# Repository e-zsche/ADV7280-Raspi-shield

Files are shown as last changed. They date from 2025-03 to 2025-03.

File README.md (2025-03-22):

# ADV7280 based analog video digitizer shield for raspberry pi

Raspberry pi shiel built around the ADV7280 analog video decoder IC. Connection to raspberry pi over
MIPI CSI-2 interface. FFC/FPC connector on the shield has the same pinout as the pi camera connector.

<p float="center">
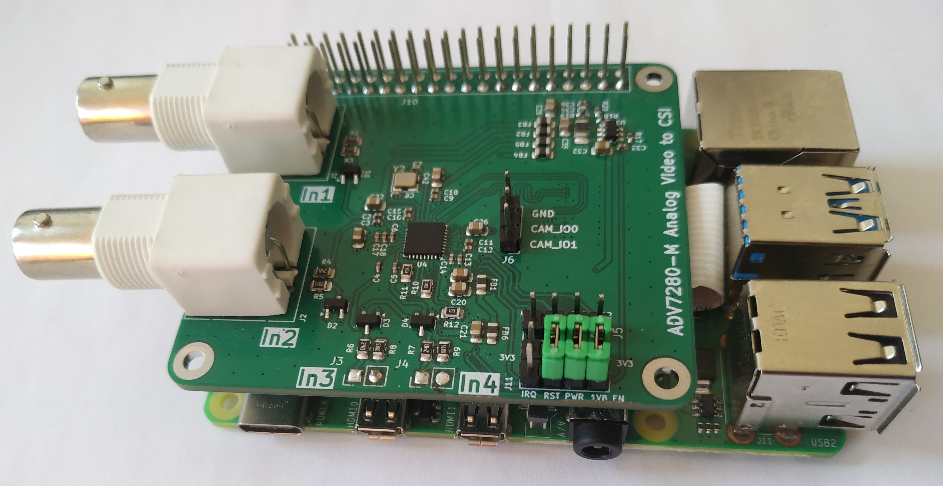
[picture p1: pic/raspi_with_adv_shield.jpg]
  
</p>

One huge advantage the ADV7280 has over similiar analog video decoders is that the drivers are already
present in the standard raspberry pi linux kernel. All you have to do is enable the driver in the
config.txt file. This shield is more or less plug'n'play.

# Hardware

The whole circuit design is copied exactly from the <a href="https://www.analog.com/media/en/technical-documentation/data-sheets/ADV7280.PDF">ADV7280 datasheet</a>

<p float="left">
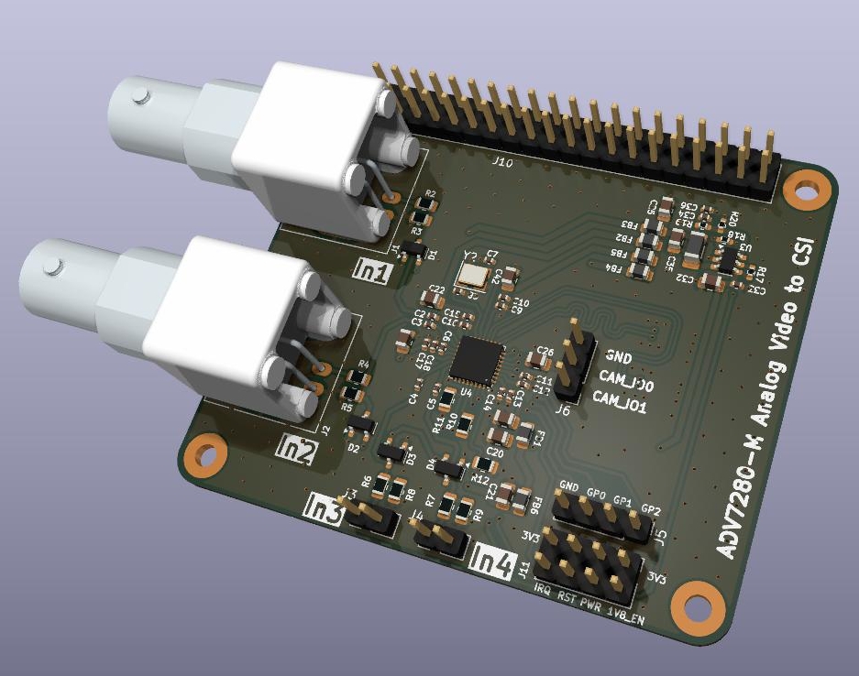
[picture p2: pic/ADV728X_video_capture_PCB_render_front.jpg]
  
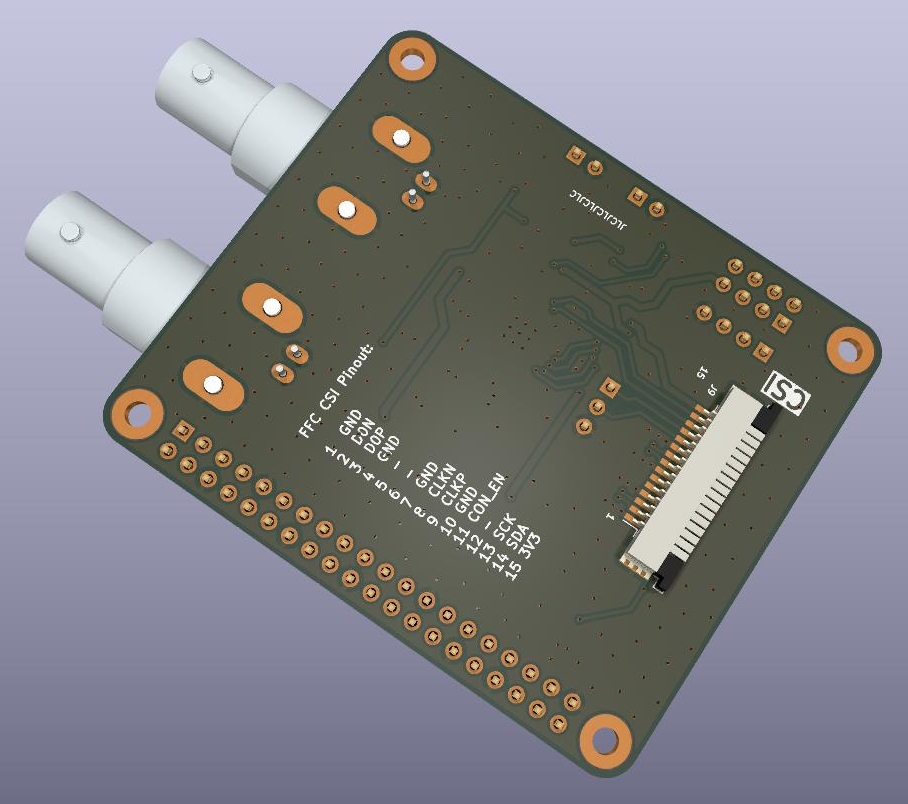
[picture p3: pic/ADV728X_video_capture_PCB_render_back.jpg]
  
</p>

Video inputs are done with BNC connectors. The only reason is that I got these really cheap so I use
them everywhere. All video inputs are terminated with 75R resistors close to the connector. For
protection there are BAT54S diodes installed on all used inputs. Because of space constraints only
inputs 1 - 4 are available on the PCB.

In the beginning I was unsure how to set the RST, PWRDWN pins of the ADV7280 and how important
the power cycling is when booting the IC. That is what the jumper pins near the raspberry pi's
USB connectors are for. Turns out you can leave them all connected to +3.3V all the time.

I was unsure about the CAM_IO1 and CAM_IO2 pins of the raspberry CSI connector as well. The pins
on the pin header can be left unconnected.

The only really critical traces in my opinion are from the CSI output from the IC to the FFC/FPC
camera connector. Looking at the technical specs in the MIPI CSI standard these traces the traces
should have 100R differential impedance (+/- 10%). To get the correct trace width and spacing I
used kicad's builtin calculation tool and the PCB dimensions of the manufacturer. With these I
fiddled around with the calculation until it was close enough.

This design is routed for ordering at JLCPCB (not sponsored!). This is important because different
manufacturers may have different PCB dimensions, which in turn affects the trace impedance of the
CSI traces. Make sure to get this correct, otherwise the CSI connection may not work reliably.

Until now the shield is running fine and I encountered no problems while running.

# Software

All connections this shield needs for running is the CSI connector to the raspberry pi's camera
interface. Enabling the kernel module for this shield is done in the config.txt file:

```
[all]
# enable adv7280
dtoverlay=adv728x-m,adv7280m=1
```

Done! After booting you should get a ne video device.
You can check this with v4l2-ctl command line utility.

```
$ v4l2-ctl --list-devices
$ v4l2-ctl -D -d 0
```

## setting video standard

Video standard is set to NTSC as default. Change it with this command
```
$ v4l2-ctl --set-standard pal
$ v4l2-ctl --set-standard ntsc
```

## changing inputs

Selecting video input source is not straight forward. This is not streamlined in the driver.
Doing this is a little bit hacky, but it works.

```
$ sudo bash -c "echo 0 > /sys/module/adv7180/parameters/dbg_input"
```

Change the number to the input you want to select. 0 corresponds to input 1 and so forth.
You can check the detected input format with

```
$ v4l2-ctl -S
```

## picture adjustment

Here is the interesting part. You can adjust brightness, saturation and so on inside the ADV7280.
No need to fiddle around with i2c registers. When the driver is loaded the corresponding i2c bus
is not exposed for reading or writing. Instead everything is handled through the v4l2-ctl utility.

To list the available settings use one of these commands:

```
$ v4l2-ctl -d <device> -l
$ v4l2-ctl -d <device> -L
```

This gives a description of all available settings and also shows the value range for each setting. If you want to change something use this command:

```
$ v4l2-ctl -d <device> -c <setting>=<value>
```

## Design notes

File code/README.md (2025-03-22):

# Even more control over picture quality

While doing picture adjustment via v4l2-ctl is fine it's not the end of it! You can have even
more control when starting to set values in the ADV7280 registers.

There is only one problem: the kernel has ownership of the I2C interface so you should not be
able to read and write directly on the bus. Well, kind of... There is a really hacky und unsafe
way to get around this. What you need is a small utility package for interfacing with i2c over
the command line.

```
sudo apt install i2c-tools
```

Inside the package are two tools that let us get access to blocked I2C busses: `i2cget` and `i2cset`.
All of this is packed in a messy python library that basically calls the command line tools and
reads the output.

As you can imagine this whole process is really messy as you never check if there is other traffic
on the bus at any time. From what I can tell the ADV7280 gets initialized by the kernel module
at boot time and afterwards it just occupies the bus with no more commands being issued. Until now
there were no crashes because of colliding I2C commands.

You can however make the chip unresponsive by setting some values in the registers. Be warned. Should
this happen and there is no response from the chip you can just reboot and everything works fine again.

## ADV7280 registers

If you want to see the registers and what they do for yourself Analog Devices published the <a href="https://www.analog.com/media/en/technical-documentation/user-guides/adv7280_7281_7282_7283_ug-637.pdf">hardware reference pdf</a>
for the ADV7280 (and similiar). Here you will find all registers with description and what they do

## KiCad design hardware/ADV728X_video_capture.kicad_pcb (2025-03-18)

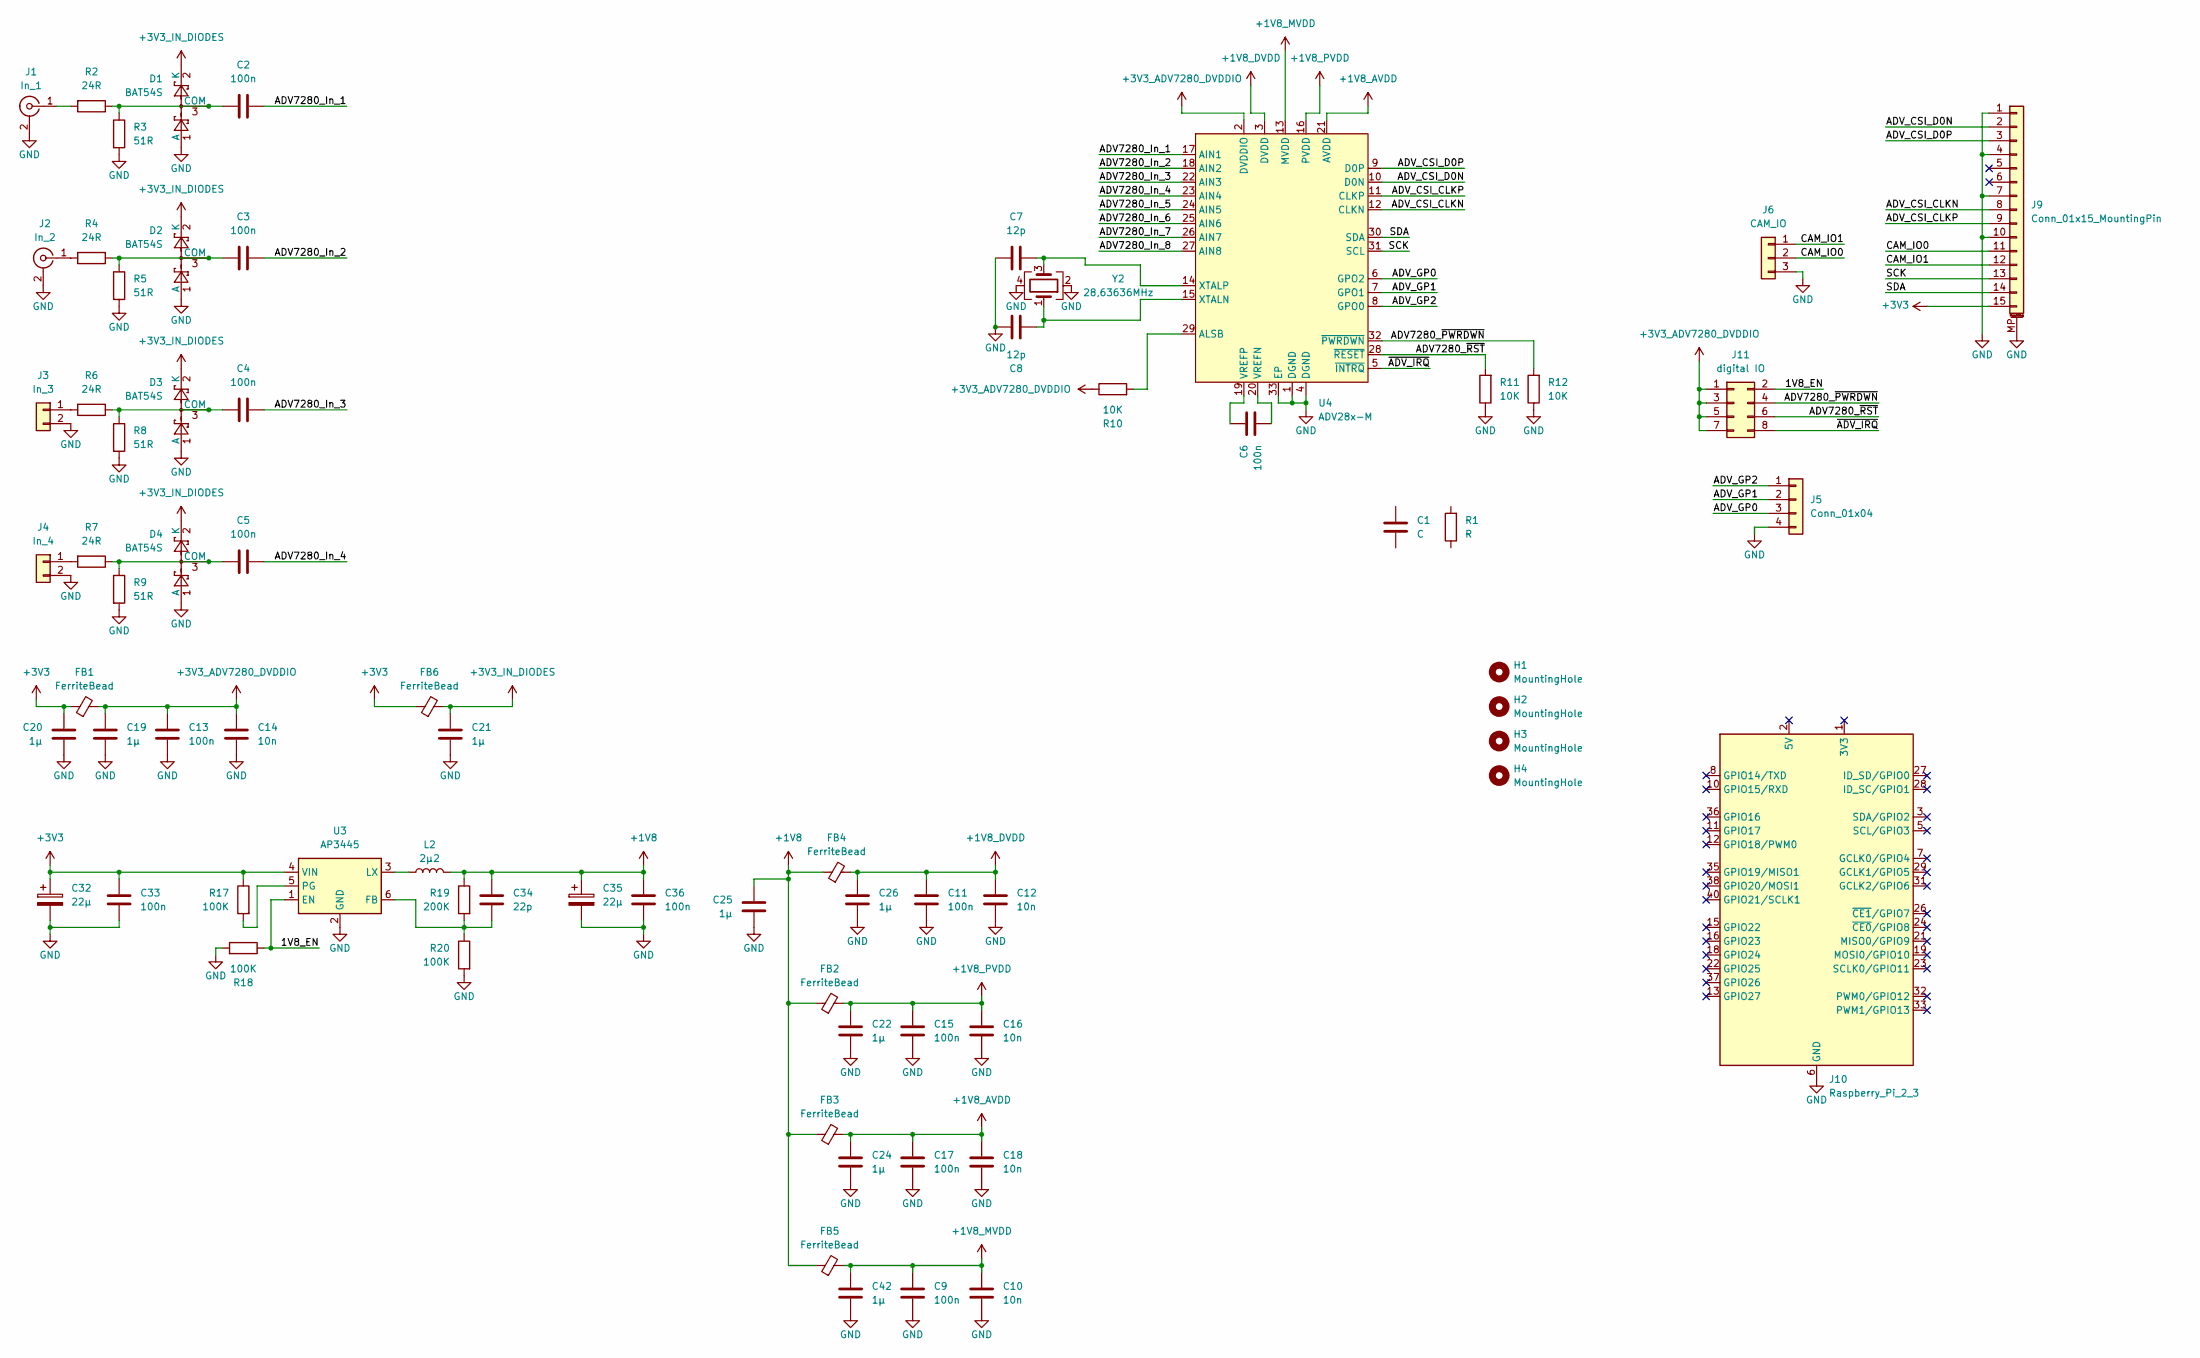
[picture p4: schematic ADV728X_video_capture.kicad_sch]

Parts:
C1: C
C2, C3, C4, C5, C6, C9, C11, C13, C15, C17, C33, C36: 100n; C_0402_1005Metric
C7, C8: 12p; C_0402_1005Metric
C10, C12, C14, C16, C18: 10n; C_0402_1005Metric
C19, C20, C21, C22, C24, C25, C26, C42: 1µ; C_0805_2012Metric
C32, C35: 22µ; C_0805_2012Metric
C34: 22p; C_0402_1005Metric
D1, D2, D3, D4: BAT54S; SOT-23
FB1, FB2, FB3, FB4, FB5, FB6: FerriteBead; L_0805_2012Metric
H1, H2, H3, H4: MountingHole; MountingHole_2.7mm_Pad
J1: In_1; BNC_Amphenol_B6252HB-NPP3G-50_Horizontal
J2: In_2; BNC_Amphenol_B6252HB-NPP3G-50_Horizontal
J3: In_3; PinHeader_1x02_P2.54mm_Vertical
J4: In_4; PinHeader_1x02_P2.54mm_Vertical
J5: Conn_01x04; PinHeader_1x04_P2.54mm_Vertical
J6: CAM_IO; PinHeader_1x03_P2.54mm_Vertical
J9: Conn_01x15_MountingPin; TE_1-84953-5_1x15-1MP_P1.0mm_Horizontal
J10: Raspberry_Pi_2_3; PinHeader_2x20_P2.54mm_Vertical
J11: digital IO; PinHeader_2x04_P2.54mm_Vertical
L2: 2µ2; L_1206_3216Metric_Pad1.22x1.90mm_HandSolder
R1: R
R2, R4, R6, R7: 24R; R_0805_2012Metric
R3, R5, R8, R9: 51R; R_0805_2012Metric
R10, R11, R12: 10K; R_0805_2012Metric
R17, R18, R20: 100K; R_0402_1005Metric_Pad0.72x0.64mm_HandSolder
R19: 200K; R_0402_1005Metric_Pad0.72x0.64mm_HandSolder
U3: AP3445; TSOT-23-6
U4: ADV28x-M; LFCSP-32-1EP_5x5mm_P0.5mm_EP3.6x3.6mm
Y2: 28,63636MHz; Crystal_SMD_3225-4Pin_3.2x2.5mm

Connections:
+1V8: C25.1, C34.1, C35.1, C36.1, FB2.1, FB3.1, FB4.1, FB5.1, L2.2, R19.1
+1V8_AVDD: C17.1, C18.1, C24.1, FB3.2, U4.21 (AVDD)
+1V8_DVDD: C11.1, C12.1, C26.1, FB4.2, U4.3 (DVDD)
+1V8_MVDD: C9.1, C10.1, C42.1, FB5.2, U4.13 (MVDD)
+1V8_PVDD: C15.1, C16.1, C22.1, FB2.2, U4.16 (PVDD)
+3V3: C20.1, C32.1, C33.1, FB1.1, FB6.1, J9.15, R17.1, U3.4 (VIN)
+3V3_ADV7280_DVDDIO: C13.1, C14.1, C19.1, FB1.2, J11.1, J11.3, J11.5, J11.7, R10.1, U4.2 (DVDDIO)
+3V3_IN_DIODES: C21.1, D1.2 (K), D2.2 (K), D3.2 (K), D4.2 (K), FB6.2
/1V8_EN: J11.2, R18.1, U3.1 (EN)
/ADV7280_In_1: C2.2, U4.17 (AIN1)
/ADV7280_In_2: C3.2, U4.18 (AIN2)
/ADV7280_In_3: C4.2, U4.22 (AIN3)
/ADV7280_In_4: C5.2, U4.23 (AIN4)
/ADV7280_In_5: U4.24 (AIN5)
/ADV7280_In_6: U4.25 (AIN6)
/ADV7280_In_7: U4.26 (AIN7)
/ADV7280_In_8: U4.27 (AIN8)
/ADV7280_~PWRDWN: J11.4, R12.2, U4.32 (~PWRDWN)
/ADV7280_~RST: J11.6, R11.2, U4.28 (~RESET)
/ADV_CSI_CLKN: J9.8, U4.12 (CLKN)
/ADV_CSI_CLKP: J9.9, U4.11 (CLKP)
/ADV_CSI_D0N: J9.2, U4.10 (D0N)
/ADV_CSI_D0P: J9.3, U4.9 (D0P)
/ADV_GP0: J5.3, U4.6 (GPO2)
/ADV_GP1: J5.2, U4.7 (GPO1)
/ADV_GP2: J5.1, U4.8 (GPO0)
/CAM_IO0: J6.2, J9.11
/CAM_IO1: J6.1, J9.12
/SCK: J9.13, U4.31 (SCL)
/SDA: J9.14, U4.30 (SDA)
/~ADV_IRQ: J11.8, U4.5 (~INTRQ)
GND: C7.1, C8.1, C9.2, C10.2, C11.2, C12.2, C13.2, C14.2, C15.2, C16.2, C17.2, C18.2, C19.2, C20.2, C21.2, C22.2, C24.2, C25.2, C26.2, C32.2, C33.2, C35.2, C36.2, C42.2, D1.1 (A), D2.1 (A), D3.1 (A), D4.1 (A), J1.2 (Ext), J2.2 (Ext), J3.2, J4.2, J5.4, J6.3, J9.1, J9.4, J9.7, J9.10, J9.MP (MountPin), J10.6 (GND), J10.9 (GND), J10.14 (GND), J10.20 (GND), J10.25 (GND), J10.30 (GND), J10.34 (GND), J10.39 (GND), R3.2, R5.2, R8.2, R9.2, R11.1, R12.1, R18.2, R20.2, U3.2 (GND), U4.1 (DGND), U4.4 (DGND), U4.33 (EP), Y2.2, Y2.4
unnamed: C2.1, D1.3 (COM), R2.1, R3.1
unnamed: C3.1, D2.3 (COM), R4.1, R5.1
unnamed: C4.1, D3.3 (COM), R6.1, R8.1
unnamed: C5.1, D4.3 (COM), R7.1, R9.1
unnamed: J1.1 (In), R2.2
unnamed: J2.1 (In), R4.2
unnamed: J3.1, R6.2
unnamed: J4.1, R7.2
unnamed: C34.2, R19.2, R20.1, U3.6 (FB)
unnamed: L2.1, U3.3 (LX)
unnamed: R17.2, U3.5 (PG)
unnamed: R10.2, U4.29 (ALSB)
unnamed: C6.2, U4.20 (VREFN)
unnamed: C6.1, U4.19 (VREFP)
unnamed: C8.2, U4.15 (XTALN), Y2.1
unnamed: C7.2, U4.14 (XTALP), Y2.3

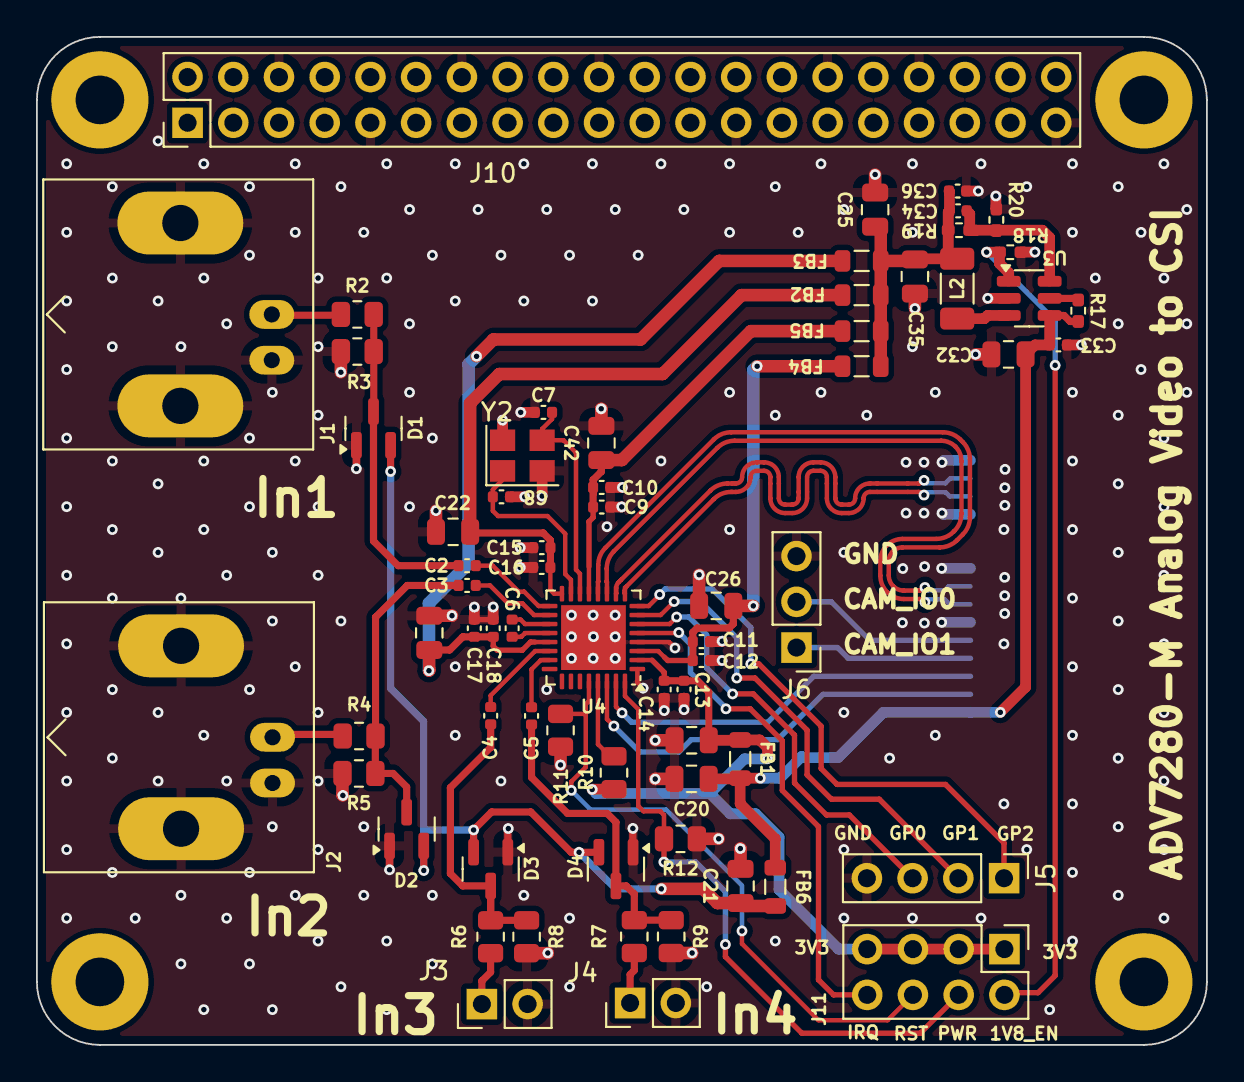
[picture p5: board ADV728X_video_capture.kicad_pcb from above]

Board: 4 copper layers, 65.0 x 56.0 mm, 72 parts (1 on the bottom side), 44 nets.

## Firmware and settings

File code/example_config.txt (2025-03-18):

# For more options and information see
# http://rptl.io/configtxt
# Some settings may impact device functionality. See link above for details

# Uncomment some or all of these to enable the optional hardware interfaces
dtparam=i2c_arm=on
#dtparam=i2s=on
#dtparam=spi=on

# Enable audio (loads snd_bcm2835)
dtparam=audio=on

# Additional overlays and parameters are documented
# /boot/firmware/overlays/README

# Automatically load overlays for detected cameras
camera_auto_detect=1

# Automatically load overlays for detected DSI displays
display_auto_detect=1

# Automatically load initramfs files, if found
auto_initramfs=1

# Enable DRM VC4 V3D driver
dtoverlay=vc4-kms-v3d
max_framebuffers=2

# Don't have the firmware create an initial video= setting in cmdline.txt.
# Use the kernel's default instead.
disable_fw_kms_setup=1

# Run in 64-bit mode
arm_64bit=1

# Disable compensation for displays with overscan
disable_overscan=1

# Run as fast as firmware / board allows
arm_boost=1

[cm4]
# Enable host mode on the 2711 built-in XHCI USB controller.
# This line should be removed if the legacy DWC2 controller is required
# (e.g. for USB device mode) or if USB support is not required.
otg_mode=1

[cm5]
dtoverlay=dwc2,dr_mode=host

[all]
# enable adv7280
dtoverlay=adv728x-m,adv7280m=1
gpu_mem=448

# Enable DRM VC4 V3D driver
# enable pal out
enable_tvout=1
sdtv_mode=2
dtoverlay=vc4-kms-v3d,composite
vc4.tv_norm=pal

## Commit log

2025-03-18 added raspi shield kicad project
    [ADV728X_video_capture.kicad_pcb, ADV728X_video_capture.kicad_sch]
2025-03-18 config.txt example for using this shield
    [example_config.txt]
2025-03-18 added rendered PCB pics
